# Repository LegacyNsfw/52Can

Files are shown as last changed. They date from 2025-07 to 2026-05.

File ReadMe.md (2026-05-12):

# 52mm CANbus Gauge Pod

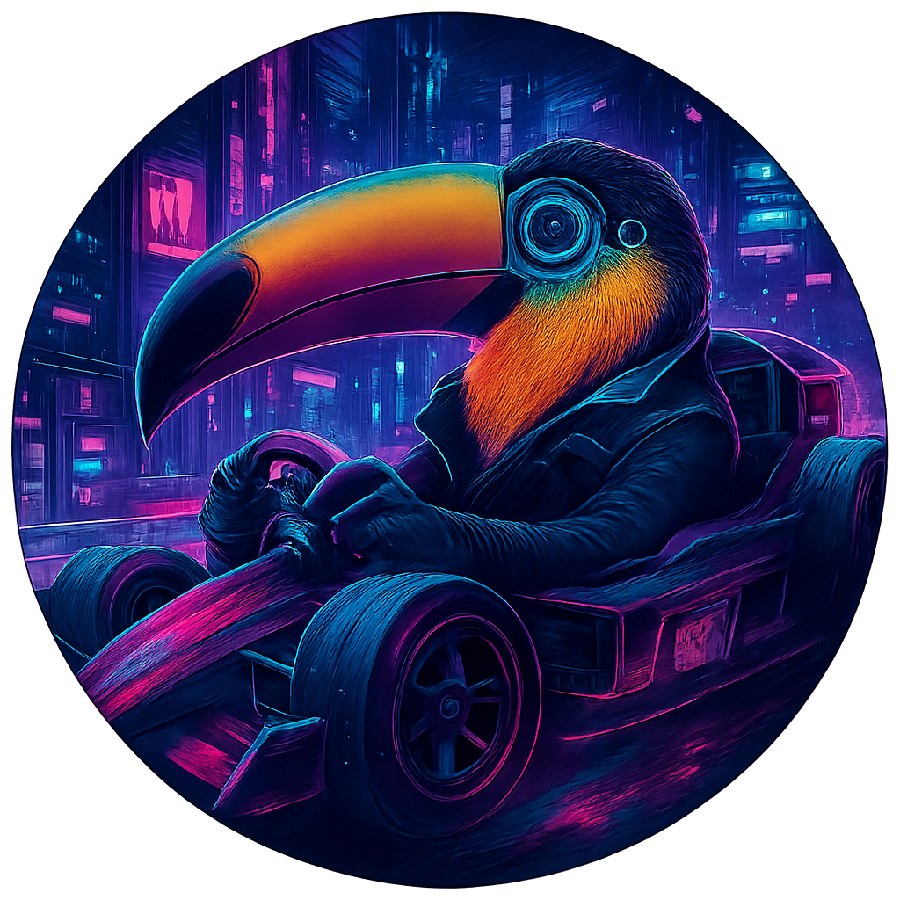
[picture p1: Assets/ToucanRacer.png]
Toucan driving a race car


# Current Situation

I've built a gauge, and it seems to work on my desk... it's in my car now. But my car's cylinder heads are at a shop across town.

If the engine was in one piece, this would probably show the AFR from the left and right banks, with seismograph-style traces that scroll from right to left. The horizontal reference lines indicate the target AFR for cruise and for power enrichment.

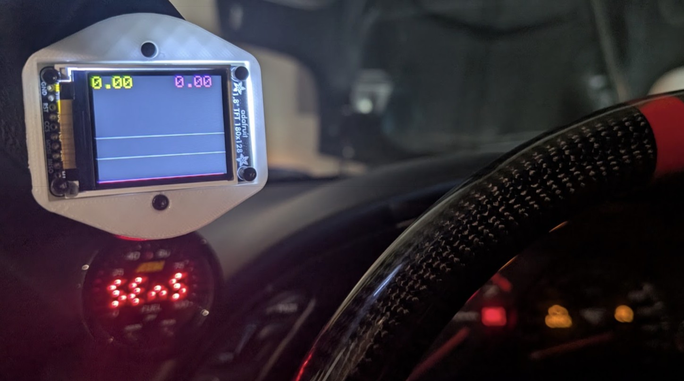
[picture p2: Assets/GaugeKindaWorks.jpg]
Gauge displaying zeroes


# Project Goals

* Display data from CAN bus.
* Fit into standard 52mm gauge pods.
* Made from inexpensive and readily available components.
* Easy to assemble - only requires basic soldering and 3D printing.
* Easy to configure...
 * For now, you'll need to be able to edit code.
 * Eventually, this should be possible with a mobile phone app.

# Designed for the following hardware:

* Processor: Seeed Studio's [Xiao ESP32C3](https://www.seeedstudio.com/Seeed-XIAO-ESP32C3-p-5431.html) ([docs](https://wiki.seeedstudio.com/XIAO_ESP32C3_Getting_Started/))  (I started with the Xiao SAMD21, but its SPI is not fast enough)
* CanBus: Seeed Studio's [Xiao CanBus expansion board](https://www.seeedstudio.com/Seeed-Studio-CAN-Bus-Breakout-Board-for-XIAO-and-QT-Py-p-5702.html) ([docs](https://wiki.seeedstudio.com/xiao-can-bus-expansion/))
* Display: Adafruit's [1.8" TFT LCD + MicroSD board](https://www.adafruit.com/product/358) ([docs](https://learn.adafruit.com/1-8-tft-display))
* Voltage regulator: [Drok Adjustable Buck Regulator](https://www.amazon.com/dp/B096RC71DC?th=1) (5 for $10)
* PCB: There are a handful of custom PCB shops, I've had good luck with [Seeed Studio Fusion](https://www.seeedstudio.com/fusion_pcb.html) (10 boards shipped to the US for $20ish in 3 weeks)
* 4-pin JST JWPF connectors [https://www.amazon.com/dp/B07VTNJLY4](Knockoffs Available Here)

# Aspirations

* Better display, perhaps using OLED. The current 1.8 TFT display works, but it isn't great.
* Perhaps a touchscreen display?
* Proper circuit board. The current board is basically just a circular solderable breadboard. It would be nice to be able to order pre-populated boards that only need power, CAN, and display wiring.
* More elegant 3D model. I did this in an afternoon. It works, but it ain't pretty.
* Android app to configure display modes, alarm thresholds, etc, with configuration [https://wiki.seeedstudio.com/xiaoesp32c3-flash-storage/](stored in flash).

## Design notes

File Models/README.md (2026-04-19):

\# Printable Gauge Pod

The pod was modeled in OpenSCAD, and downloadble STL files are provided for convenience.

IMPORTANT: The base of the gauge pod was modeled upside-down for ease of printing. 

The circuit board mounts on the opposite side from the display, and the notch in the side allows access to the USB-C port for programming.

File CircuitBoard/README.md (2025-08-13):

\# DO NOT USE

This is very flawed. I did manage to build a functioning gauge with this design, but it's far more difficult than it should be, for a few reasons...

To-do list for the next iteration:

* move actual (solder) Xiao pin rows very slightly further apart, so the Xiao fits properly.
* move upper/inner pin row (U1) to the outside (currently they're UNDER the Xiao)
* add a new extra/outer row at the top
* make the board double-sided
* move everything down a little
* add 1 more pin to the rows, on the side furthest from the edge
* link all 7 Xiao pins to the outside rows (not just the two that were intended for power)
* link the 5 outside non-Xiao pins to the outside rows (for the power supply)

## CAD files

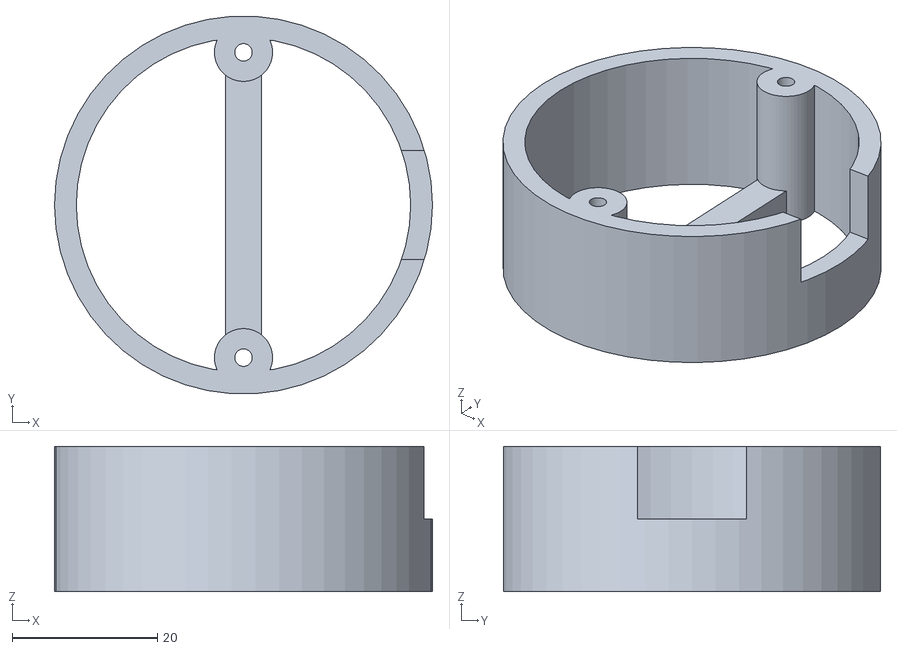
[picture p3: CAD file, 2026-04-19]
Models/Base.stl
52.0 x 51.9 x 20.0

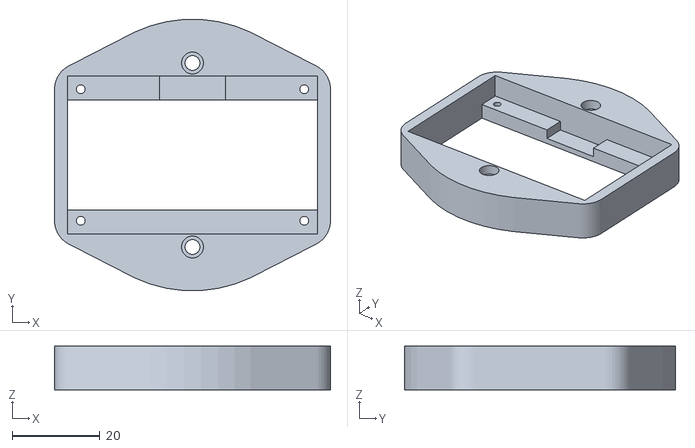
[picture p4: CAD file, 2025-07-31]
Models/Top.stl
63.0 x 61.9 x 10.0

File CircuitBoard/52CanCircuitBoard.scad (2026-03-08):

boardRadius = 25;
boltRadius = 1.3;
boltPosition = 21;
reliefRadius = 2.5;

$fn = 100;

projection()
translate([0, 0, 10])
difference()
{
    // plate
    cylinder(h = 1, r1 = boardRadius, r2 = boardRadius, center = true);
    
    // mounting bolts
    translate([boltPosition, 0, 0])
        cylinder(h = 2, r1 = boltRadius, r2 = boltRadius, center = true);
    translate([-boltPosition, 0, 0])
        cylinder(h = 2, r1 = boltRadius, r2 = boltRadius, center = true);
    
    // strain relief
    translate([0, 17, 0])
    {
        cylinder(h = 2, r1 = reliefRadius, r2 = reliefRadius, center = true);
        translate([10, 0, 0])
            cylinder(h = 2, r1 = reliefRadius, r2 = reliefRadius, center = true);
        translate([-10, 0, 0])
            cylinder(h = 2, r1 = reliefRadius, r2 = reliefRadius, center = true);           
    }
}

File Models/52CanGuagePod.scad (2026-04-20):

$fn = 50;

podRadius = 52/2;
podDepth = 20;
podHoleRadius = 23;
bezelRadius = podRadius + 5;
bezelHeight = 10;

// Adafruit 1.8" display with EYESPI
boardWidth = 57;
boardDepth = 36;
boardThickness = 6.5;
holeX = 25.5;
holeY = 15;
cornerRadius = 6;

boltPosition = 21;

/*
// zio.cc 1.5"
screenWidth = 30;
screenDepth = 34;
screenThickness = 1.5;

boardWidth = 45;
boardDepth = 36;
boardThickness = 1;
*/

module top()
{
    difference() {
        hull() {
            translate([0, 0, bezelHeight / 2])
                cylinder(h = bezelHeight, r = bezelRadius, center = true);
            
            translate([holeX, holeY, bezelHeight / 2])
                cylinder(h = bezelHeight, r = cornerRadius, center = true);
            translate([-holeX, holeY, bezelHeight / 2])
                cylinder(h = bezelHeight, r = cornerRadius, center = true);
            translate([holeX, -holeY, bezelHeight / 2])
                cylinder(h = bezelHeight, r = cornerRadius, center = true);
            translate([-holeX, -holeY, bezelHeight / 2])
                cylinder(h = bezelHeight, r = cornerRadius, center = true);
        }
        
        translate([holeX, holeY, 0])
            cylinder(h = bezelHeight, r = 1, center = true);
        translate([-holeX, holeY, 0])
            cylinder(h = bezelHeight, r = 1, center = true);
        translate([holeX, -holeY, 0])
            cylinder(h = bezelHeight, r = 1, center = true);
        translate([-holeX, -holeY, 0])
            cylinder(h = bezelHeight, r = 1, center = true);
        
        // cutout
        translate([0, 0, 2.9])
            cube([boardWidth, 25, 6], center = true);

        // bolts
        translate([0, boltPosition, 0])
            cylinder(h = 100, r = 1.7, center = true);
        translate([0, -boltPosition, 0])
            cylinder(h = 100, r = 1.7, center = true);

        // bolt heads
        translate([0, boltPosition, 9])
            cylinder(h = 3, r = 2.5, center = true);
        translate([0, -boltPosition, 9])
            cylinder(h = 3, r = 2.5, center = true);

        // ribbon connector
        translate([0, 15, 3])
            cube([15, 6, 3], center = true);
    }    

}

module display()
{
    translate([0, 0, boardThickness / 2])
        cube([boardWidth, boardDepth, boardThickness], center = true);
}

module base()
{
    difference() {
        union () {
            // bolt bosses
            translate([0, boltPosition, -podDepth / 2])
                cylinder(h = podDepth, r = 4, center = true);
            translate([0, -boltPosition, -podDepth / 2])
                cylinder(h = podDepth, r = 4, center = true);
            
            // crossbar
            translate([0, 0, -podDepth + 2.5])
                rotate([0, 0, 90])
                cube([podRadius * 2 - 2, 5, 5], center = true);
            
            // sleeve
            difference(){
                union () {
                    translate([0, 0, -podDepth / 2])
                        cylinder(h = podDepth, r = podRadius, center = true);
                }
                cylinder (h = 100, r = podHoleRadius, center = true);
            }
        }
        
        // bolt holes
        translate([0, boltPosition, 0])
            cylinder(h = 100, r = 1.2, center = true);
        translate([0, -boltPosition, 0])
            cylinder(h = 100, r = 1.2, center = true);
        
        // USB-C port
        translate([boltPosition, 0, 0])
            cube([10,15,20], center = true);
    }
}

// You'll probably want to comment out the top() or bottom() to print them separately.
difference() {
    union () {
        //top();
        base();
    }
    translate([0, 0, 4])
        display();
}

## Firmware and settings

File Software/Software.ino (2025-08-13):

#include <Arduino_GFX_Library.h>
#include "Constants.h"
#include "Test.h"
#include "History.h"
#include "DisplayComponent.h"
#include "CanComponent.h"
#include "MockAfrData.h"

History *pLeftHistory = nullptr;
History *pRightHistory = nullptr;
DisplayComponent *pDisplayComponent = nullptr;
CanComponent *pCanComponent = nullptr;
MockAfrData *pMockAfrData = nullptr;

int lastKnock = 0;
int loopCount = 0;

void wait() {
  delay(250);
  yield();
}

void setup() {  
  // Wait for the serial port to be available.
  Serial.begin(115200);
  while(!Serial);

  // An extra pause, just to ensure that the serial port is ready.
  wait();
  Serial.println();
  Serial.println(F("52Can self-test starting. #################################"));
  TestHistory();

  Serial.println(F("History component initializing. ##########################"));
  pLeftHistory = new History(width);
  pLeftHistory->initialize();

  pRightHistory = new History(width);
  pRightHistory->initialize();

  Serial.println(F("Display component initializing. ##########################"));
  pDisplayComponent = new DisplayComponent();
  pDisplayComponent->initialize();

  Serial.println(F("CAN component initializing. ###############################"));
  pCanComponent = new CanComponent();

#ifdef MOCK_DATA
  Serial.println(F("Mock AFR data component initializing. ####################"));
  pMockAfrData = new MockAfrData();
  pMockAfrData->initialize();
#else  
  pCanComponent->initialize();
#endif 

  Serial.println(F("Initialization complete. ##################################"));
}

int knockDisplayCount = 0;
int temperatureDisplayCount = 0;
int pressureDisplayCount = 0;

int ConsiderAlarm(int predicate, int mockRandomizer, int &displayCount, int value, const char* label, int textColor, int backgroundColor) {
#ifdef MOCK_DATA
  predicate = predicate || (loopCount % mockRandomizer == 1);
#endif
  if (predicate || (displayCount > 0)) {
    pDisplayComponent->drawAlarm(value, (char*)label, textColor, backgroundColor);
    if (predicate) {
      displayCount = 10; // Show for 10 loops
    } else {
      displayCount--;
    }
    return 1; // Alarm shown
  }
  return 0; // No alarm shown
}

void loop() {
  loopCount++;
  
#ifdef MOCK_DATA  
  pMockAfrData->loop();
  pLeftHistory->push(pMockAfrData->value1);
  pRightHistory->push(pMockAfrData->value2);  
#else
  canComponent->loop();
  pLeftHistory->push(pCanComponent->lambda1);
  pRightHistory->push(pCanComponent->lambda2);
#endif

#ifdef GAUGE_COMBINATION_ALARM  
  int temperature = pCanComponent->temperature;
  int pressure = pCanComponent->pressure;
  int knock = pCanComponent->knock;

  int knockIncreased = (knock > lastKnock);
  lastKnock = knock;
  if (ConsiderAlarm(knockIncreased, 100, knockDisplayCount, knock, "Knock", WTF_BLACK, WTF_WHITE))
  {
    return;
  }

  int temperatureAlarm = (temperature > 270);
  if (ConsiderAlarm(temperatureAlarm, 37, temperatureDisplayCount, temperature, "Oil Temp.", WTF_WHITE, WTF_RED))
  {
    return;
  }

  int pressureAlarm = 0; // (pressure < 56);
  if (ConsiderAlarm(pressureAlarm, 182, pressureDisplayCount, pressure, "Fuel Press.", WTF_WHITE, WTF_BLUE))
  {
    return;
  }

  pDisplayComponent->draw(pLeftHistory, pRightHistory);
#endif

#ifdef GAUGE_DUAL_AFR
  pCanComponent->loop();
  pLeftHistory->push(pCanComponent->lambda1);
  pRightHistory->push(pCanComponent->lambda2);
  pDisplayComponent->draw(pLeftHistory, pRightHistory);
#endif
}

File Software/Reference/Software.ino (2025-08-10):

#include "Constants.h"
#include "History.h"
#include "DisplayComponent.h"
//#include "CanComponent.h"


void wait() {
  delay(250);
  yield();
}

int value;
int rise;
int drawMax;
long iteration;

DisplayComponent* pDisplayComponent;
//CanComponent* canComponent;
History* history;

void setup() 
{
  // Wait for the serial port to be available, then announce startup.
  Serial.begin(115200);
  while(!Serial);
  wait();
  wait();
  Serial.println();
  Serial.println(F("CAN Display starting. #####################################"));
  
  Serial.println(F("Step 1: Initializing variables..."));

  // Initialize variables that depend on width/height
  value = height / 2;
  drawMax = height / 2;
  rise = 1;
  Serial.println(F("Variables initialized."));
  
  Serial.println(F("Step 2: Creating DisplayComponent..."));
  pDisplayComponent = new DisplayComponent();
  Serial.println(F("DisplayComponent created."));
  
  //Serial.println(F("Step 3: Creating CanComponent..."));
  //canComponent = new CanComponent();
  //Serial.println(F("CanComponent created."));
  
  Serial.println(F("Step 4: Creating History..."));
  Serial.print(F("Free heap before History creation: "));
  Serial.println(ESP.getFreeHeap());
  
  history = new History(width);
  Serial.println(F("History created."));
  
  Serial.print(F("Free heap after History creation: "));
  Serial.println(ESP.getFreeHeap());

  /*
  Serial.print("MOSI: ");
  Serial.println(MOSI);
  Serial.print("MISO: ");
  Serial.println(MISO);
  Serial.print("SCK: ");
  Serial.println(SCK);
  Serial.print("SS: ");
  Serial.println(SS);
  */  

  //canComponent->initialize();

  Serial.println(F("Step 5: Initializing DisplayComponent..."));
  pDisplayComponent->initialize();
  Serial.println(F("DisplayComponent initialized."));

  Serial.println("Empty history:");
  history->debug();
  Serial.println("Initializing history.");
  Serial.print(F("About to fill buffer with "));
  Serial.print(width);
  Serial.println(F(" values..."));
  
  // Fill the history buffer with fake data.
  for (int i = 0; i < width; i++)
  {
    if (i % 32 == 0) {  // Print progress every 32 iterations
      Serial.print(F("Filling index "));
      Serial.print(i);
      Serial.print(F(", free heap: "));
      Serial.println(ESP.getFreeHeap());
    }
    history->push(height / 2);
  }

  Serial.println(F("Initialized history:"));
  history->debug();
  
  Serial.println(F("Setup complete. #############################################"));
}

void loop() {
  Serial.print(F("Start "));
  Serial.print(iteration++);
  Serial.println();

  Serial.println(F("Update state."));
  wait();
  if (value == height)
  {
    rise = 0; 
  }
  else if (value == 0)
  {
    rise = 1;
  }

  if (rise == 1)
  {
    value+=1;
  }
  else 
  {
    value-=1;
  }

  Serial.println(F("B"));
  wait();

  history->push(value); // This causes the CPU to crash.
  history->debug();

  Serial.println(F("C"));
  wait();
  
  pDisplayComponent->draw(history, 0); // canComponent.temperature);
  //canComponent->loop();
  Serial.println(F("Z"));
  
  wait();
}

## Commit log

2025-07-31 Starting over
    [52Can.fzz, 52CanCircuitBoard.scad, 52CanGuagePod.scad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]
2025-08-01 Added test support, fixed issue in History implementation.
    [DisplayComponent.cpp, History.cpp, Software.ino]
2025-08-05 Dual trace
2025-08-05 CAN temperature works. Need better font.
2025-09-08 Flattening directory structure a bit
    [52Can.fzz, 52CanCircuitBoard.scad, 52CanGuagePod.scad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]
2026-03-08 Moved passthrough holes 2mm outward, breadboarded the pins nearest the holes.
    [52Can.fzz, 52CanCircuitBoard.scad]
2026-04-18 Added 3 more rows of holes for future expansion.
    [52Can.fzz]
2026-04-19 Added notch for USB-C port access
    [52CanGuagePod.scad, Base.stl]
2026-04-20 Unsaved changes meant for the previous commit.
    [52CanGuagePod.scad]
2026-05-12 Update ReadMe with current status and aspirations
    Added additional details about the current gauge functionality and aspirations for future improvements.
